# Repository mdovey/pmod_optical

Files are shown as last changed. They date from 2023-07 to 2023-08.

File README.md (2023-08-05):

# pmod_optical
#### PMOD to Optical (ADAT/SPDIF) Module

 

PMOD module for interfacing with optical fibres using the JIS F05 connector (up to 16mbps). Typical applications are for digital audio using SPDIF (2 Channel) or ADAT (4/8 Channels).

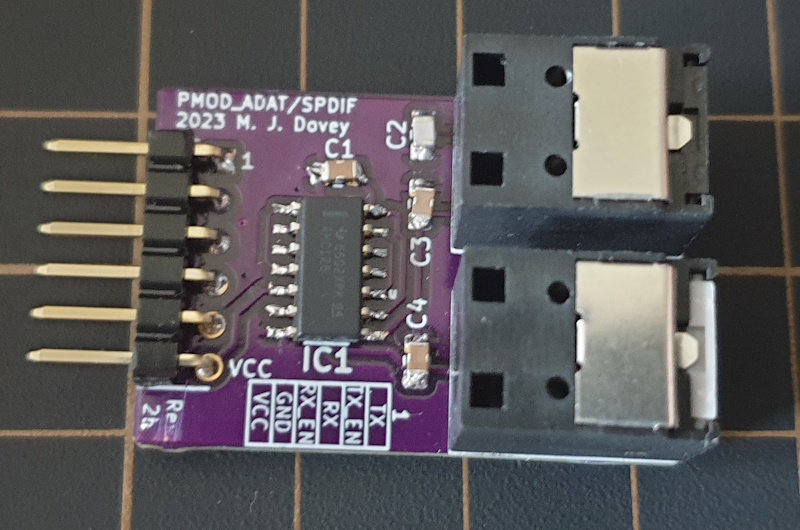
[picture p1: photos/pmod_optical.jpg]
pmod_optical


| PMOD Pin | Name  | Direction | Description |
| --- | ----- | --- | --- |
| 1 | TX | Out | Optical transmitter data |
| 2 | TX_EN | Out | Enable the optical transmitter |
| 3 | RX | In | Optical receiver data |
| 4 | RX_EN | Out | Enable the optical receiver |

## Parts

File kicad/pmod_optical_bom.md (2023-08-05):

# pmod_optical.kicad_sch BOM

05/08/2023 13:05:41

Generated from schematic by Eeschema 7.0.6

**Component Count:** 16

| Refs | Qty | Component | Description | Manufacturer | MPN | Notes |
| ----- | --- | ---- | --- | ---- | ---- | ---- |
| C1, C3, C4 | 3 | 0.1uF | Unpolarized capacitor |  | 0.1uF 0805 SMD Capacitor |  |
| C2 | 1 | 30pF | Unpolarized capacitor |  | 30pf 0805 SMD Capacitor |  |
| IC1 | 1 | SN74AHC126DR | Quadruple Bus Buffer Gates With 3-State Outputs | Texas Instruments | [SN74AHC126DR](https://www.ti.com/lit/gpn/SN74AHC126) | SOIC SMD SN74AHC126DR |
| J1 | 1 | PMOD (6 Pin) | Digilent 6 Pin PMOD Connector | Samtec | [TSW-106-08-L-S-RA](https://suddendocs.samtec.com/catalog_english/tsw_th.pdf)) | 1x6 0.1 Inch pitch right angle pin header |
| J2 | 1 | FCR684208R | Cliff Electronic Components Optical Receiver | Cliff Electronics Components | [FCR684208R](https://www.cliffuk.co.uk/products/optical/FCR684208R.pdf) |  |
| J3 | 1 | FCR684208T | Cliff Electronic Components Optical Transmitter | Cliff Electronics Components | [FCR684208T](https://www.cliffuk.co.uk/products/optical/FCR684208T.pdf) |  |
| R1–8 | 8 | 100k | Resistor |  | 100k ohm 0805 SMD Resistor |  |

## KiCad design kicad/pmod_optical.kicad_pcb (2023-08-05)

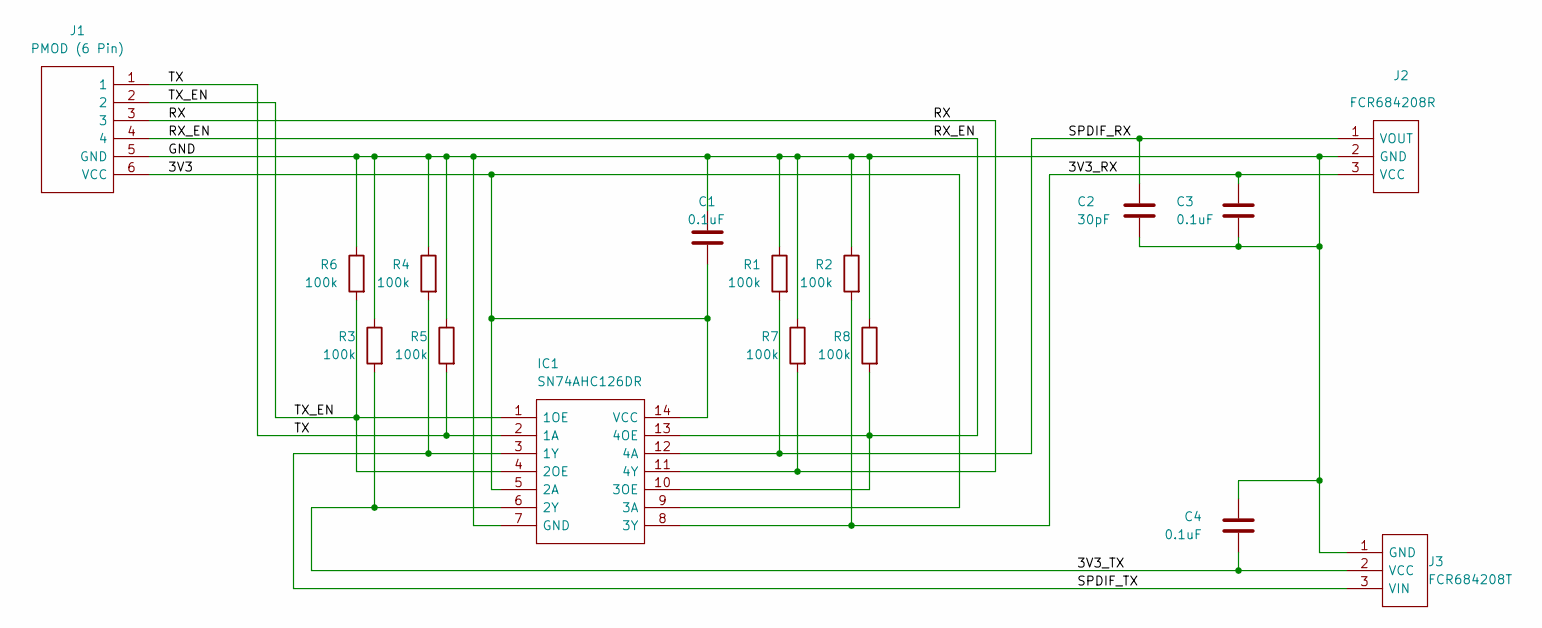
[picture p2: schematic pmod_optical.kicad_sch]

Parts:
C1, C3, C4: 0.1uF; C_0805_2012Metric_Pad1.18x1.45mm_HandSolder; MPN 0.1uF 0805 SMD Capacitor
C2: 30pF; C_0805_2012Metric_Pad1.18x1.45mm_HandSolder; MPN 30pf 0805 SMD Capacitor
IC1: SN74AHC126DR; SOIC_SN74AHC126DR; MPN SN74AHC126DR
J1: PMOD (6 Pin); MPN TSW-106-08-L-S-RA
J2: FCR684208R; MPN FCR684208R
J3: FCR684208T; MPN FCR684208T
R1, R2, R3, R4, R5, R6, R7, R8: 100k; R_0805_2012Metric_Pad1.20x1.40mm_HandSolder; MPN 100k ohm 0805 SMD Resistor

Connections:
/3V3: C1.1, IC1.5 (2A), IC1.9 (3A), IC1.14 (VCC), J1.6 (VCC); also elsewhere on the board
/3V3_RX: C3.1, IC1.8 (3Y), J2.3 (VCC), R2.2
/3V3_TX: C4.1, IC1.6 (2Y), J3.2 (VCC), R3.2
/GND: C1.2, C2.2, C3.2, C4.2, IC1.7 (GND), J1.5 (GND), J2.2 (GND), J3.1 (GND), R1.1, R2.1, R3.1, R4.1, R5.1, R6.1, R7.1, R8.1; also elsewhere on the board
/RX: IC1.11 (4Y), J1.3, R7.2; also elsewhere on the board
/RX_EN: IC1.10 (3OE), IC1.13 (4OE), J1.4, R8.2; also elsewhere on the board
/SPDIF_RX: C2.1, IC1.12 (4A), J2.1 (VOUT), R1.2
/SPDIF_TX: IC1.3 (1Y), J3.3 (VIN), R4.2
/TX: IC1.2 (1A), J1.1, R5.2; also elsewhere on the board
/TX_EN: IC1.1 (1OE), IC1.4 (2OE), J1.2, R6.2; also elsewhere on the board

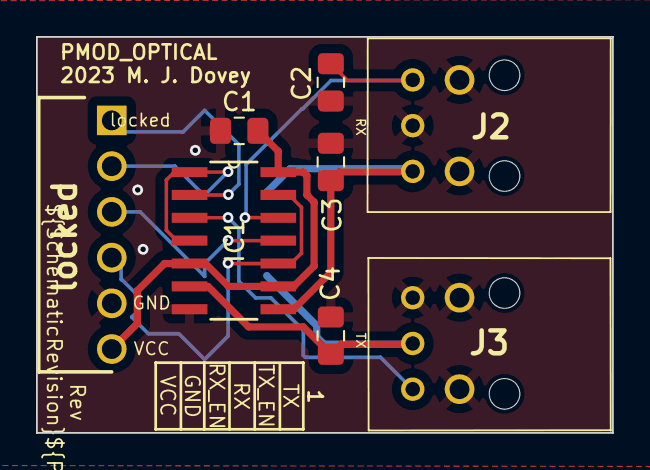
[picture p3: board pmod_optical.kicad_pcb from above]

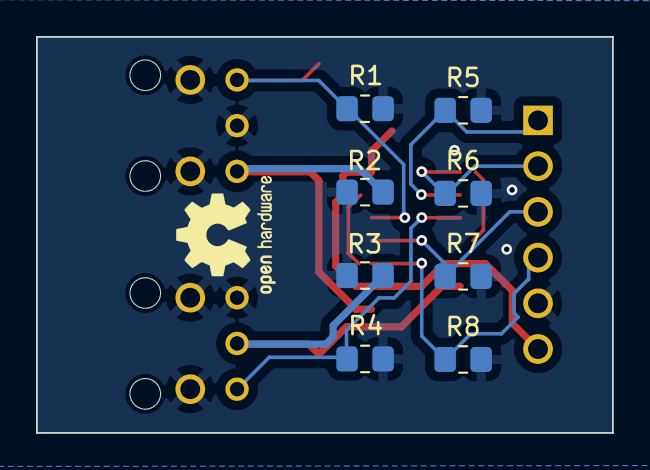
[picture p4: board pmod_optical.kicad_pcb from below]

Board: 2 copper layers, 32.0 x 22.0 mm, 16 parts (8 on the bottom side), 10 nets.

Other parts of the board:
locked: PMOD (6 Pin)

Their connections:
/3V3: locked.6 (VCC); also elsewhere on the board
/GND: locked.5 (GND); also elsewhere on the board
/RX: locked.3; also elsewhere on the board
/RX_EN: locked.4; also elsewhere on the board
/TX: locked.1; also elsewhere on the board
/TX_EN: locked.2; also elsewhere on the board

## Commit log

2023-07-26 Initial pcb layout
    [pmod_optical.kicad_pcb, pmod_optical.kicad_sch]
2023-07-27 Added BOM
    [pmod_optical.kicad_pcb, pmod_optical.kicad_sch]
2023-08-05 Update BOM
    [pmod_optical.kicad_pcb, pmod_optical.kicad_sch]

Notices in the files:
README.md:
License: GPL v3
